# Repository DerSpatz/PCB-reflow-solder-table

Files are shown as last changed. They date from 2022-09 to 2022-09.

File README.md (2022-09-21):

# PCB-reflow-solder-table
Table version of the PCB heat plate with advanced features and swappable heat plate

This design is not yet tested and was not built yet.
Currently there's no firmware yet. I am not able to write the code, so feel free to contribute.
 
Schematic is pretty well documented, you can find most info you'll need there.

Todo:
- write firmware
- check actual mechanical device
- write better readme ;-)

Send me a message if you need gerbers for the actual heat plate.

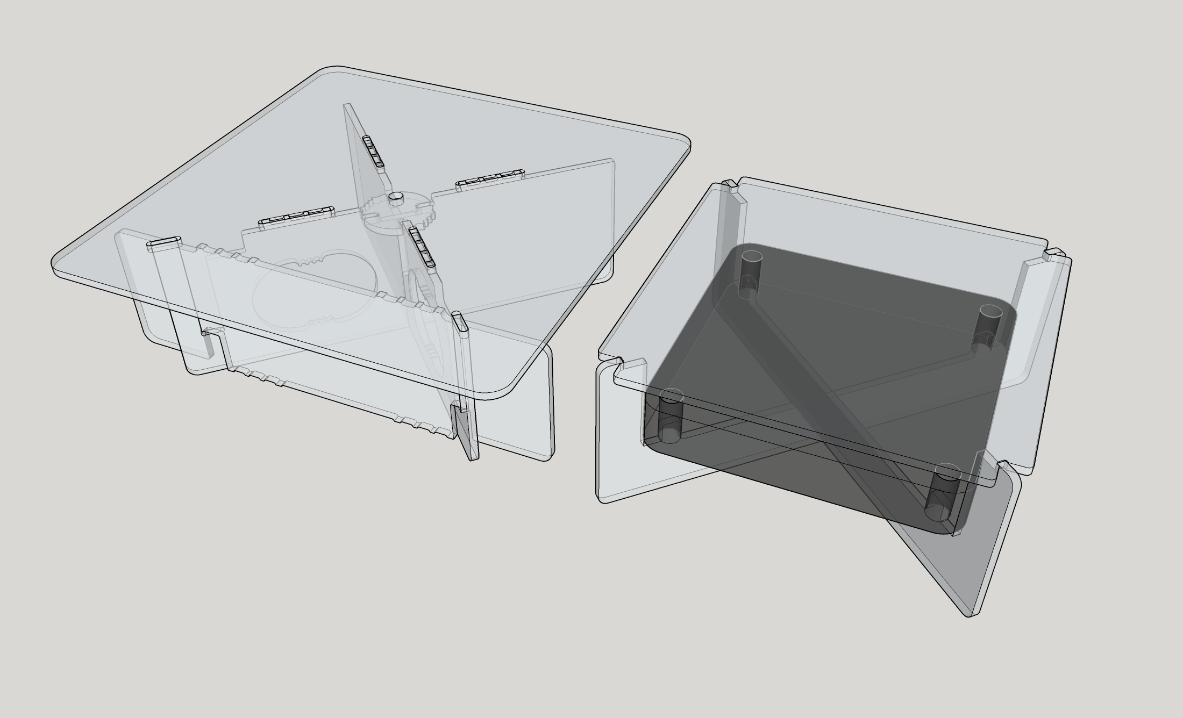
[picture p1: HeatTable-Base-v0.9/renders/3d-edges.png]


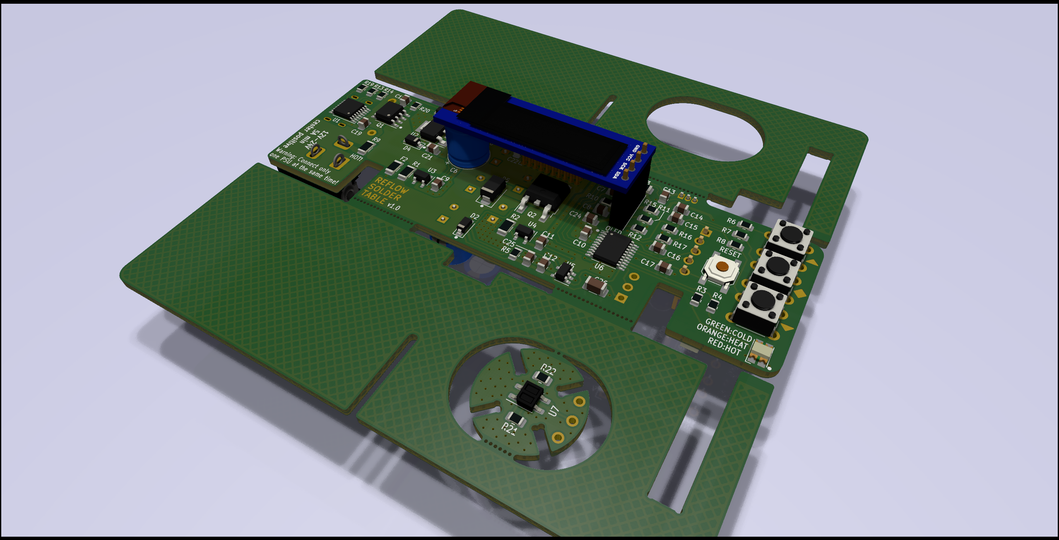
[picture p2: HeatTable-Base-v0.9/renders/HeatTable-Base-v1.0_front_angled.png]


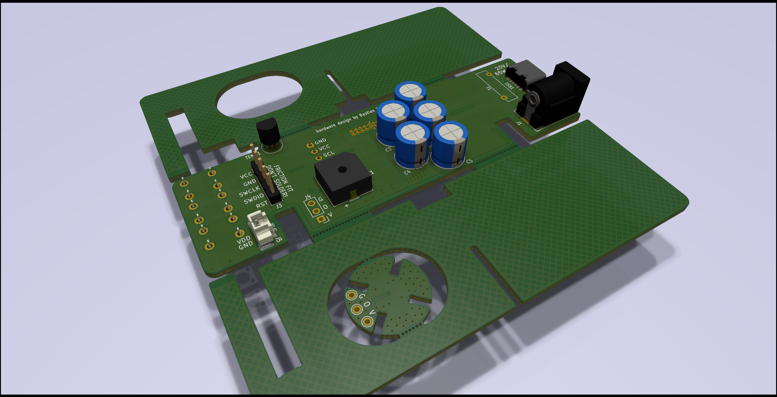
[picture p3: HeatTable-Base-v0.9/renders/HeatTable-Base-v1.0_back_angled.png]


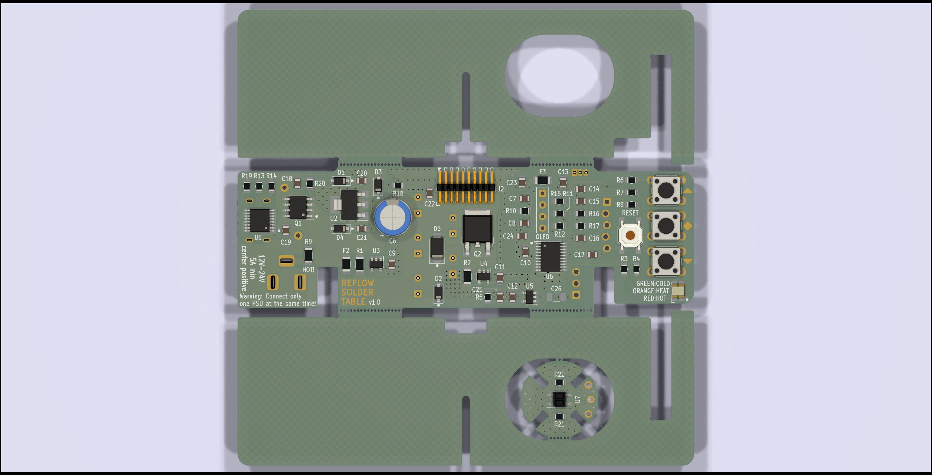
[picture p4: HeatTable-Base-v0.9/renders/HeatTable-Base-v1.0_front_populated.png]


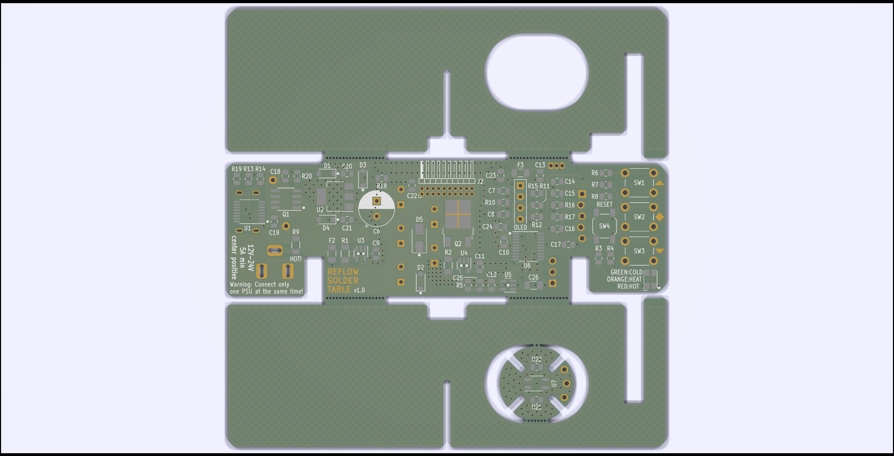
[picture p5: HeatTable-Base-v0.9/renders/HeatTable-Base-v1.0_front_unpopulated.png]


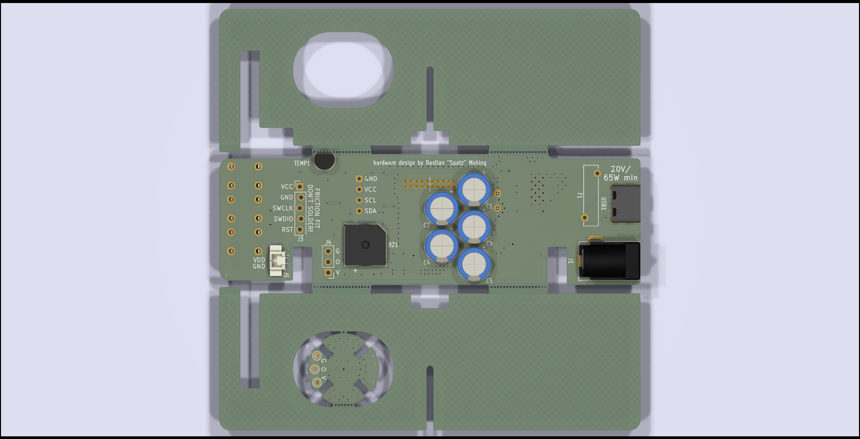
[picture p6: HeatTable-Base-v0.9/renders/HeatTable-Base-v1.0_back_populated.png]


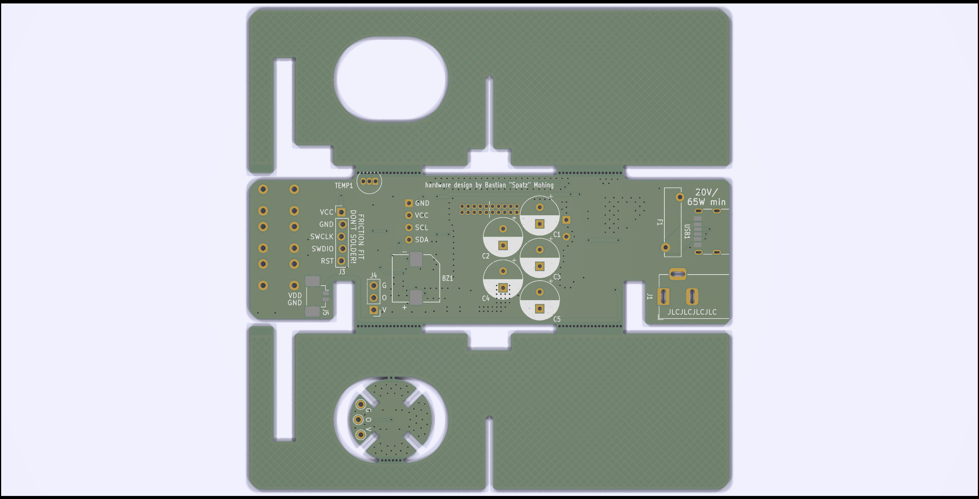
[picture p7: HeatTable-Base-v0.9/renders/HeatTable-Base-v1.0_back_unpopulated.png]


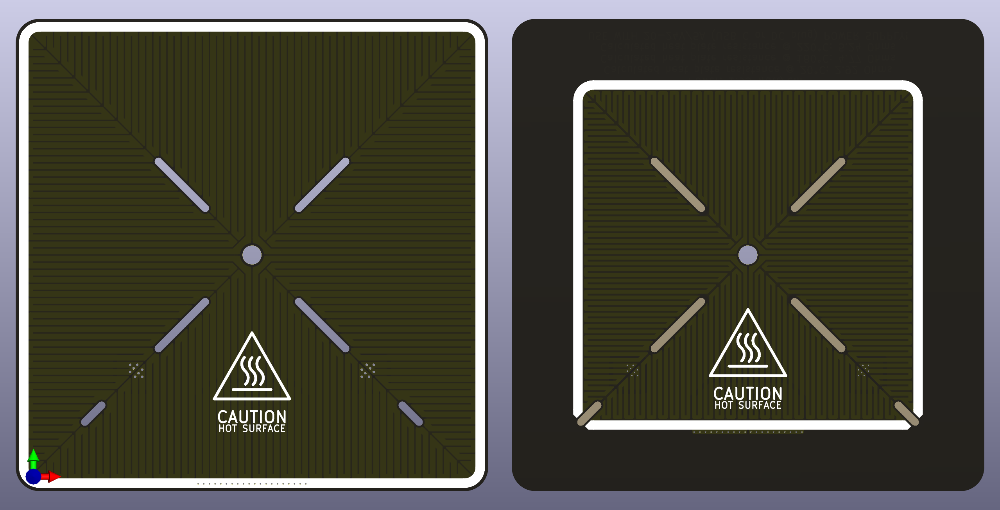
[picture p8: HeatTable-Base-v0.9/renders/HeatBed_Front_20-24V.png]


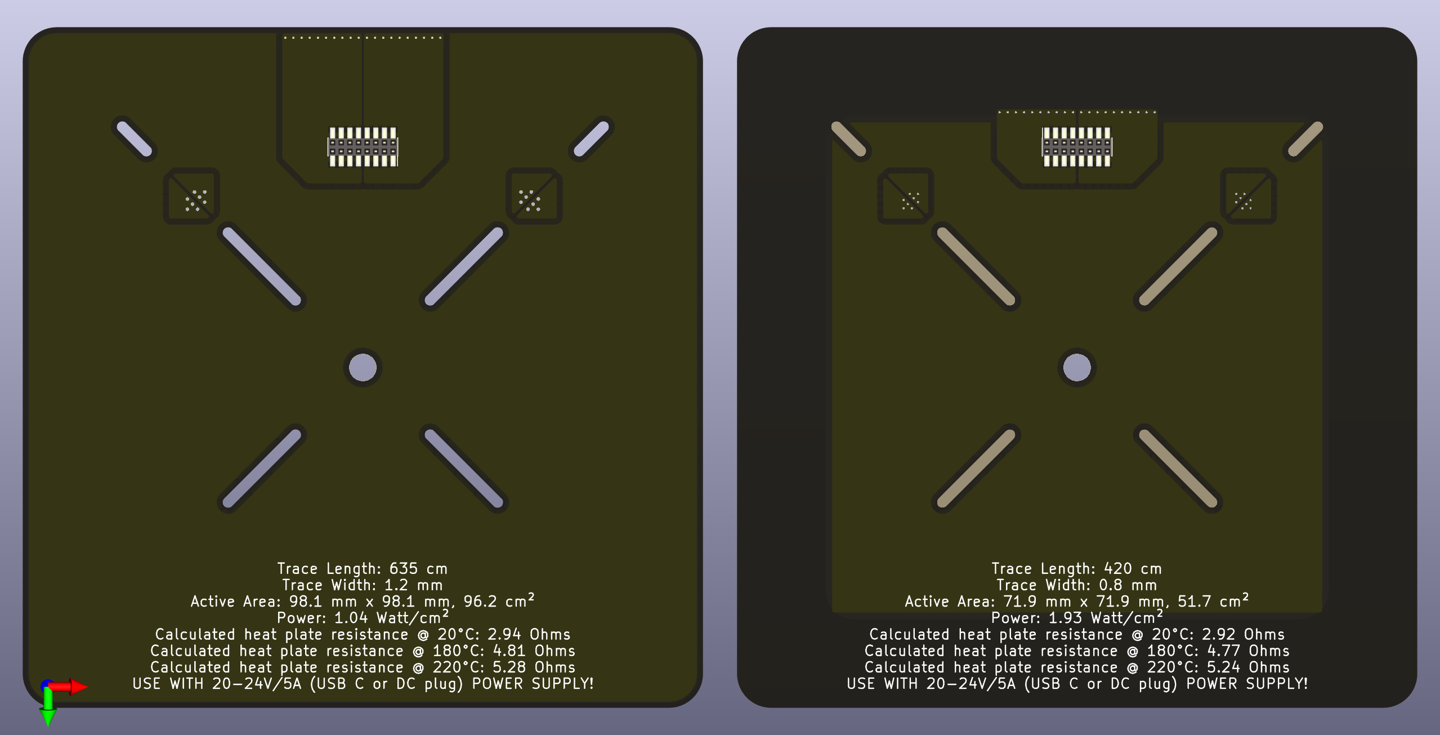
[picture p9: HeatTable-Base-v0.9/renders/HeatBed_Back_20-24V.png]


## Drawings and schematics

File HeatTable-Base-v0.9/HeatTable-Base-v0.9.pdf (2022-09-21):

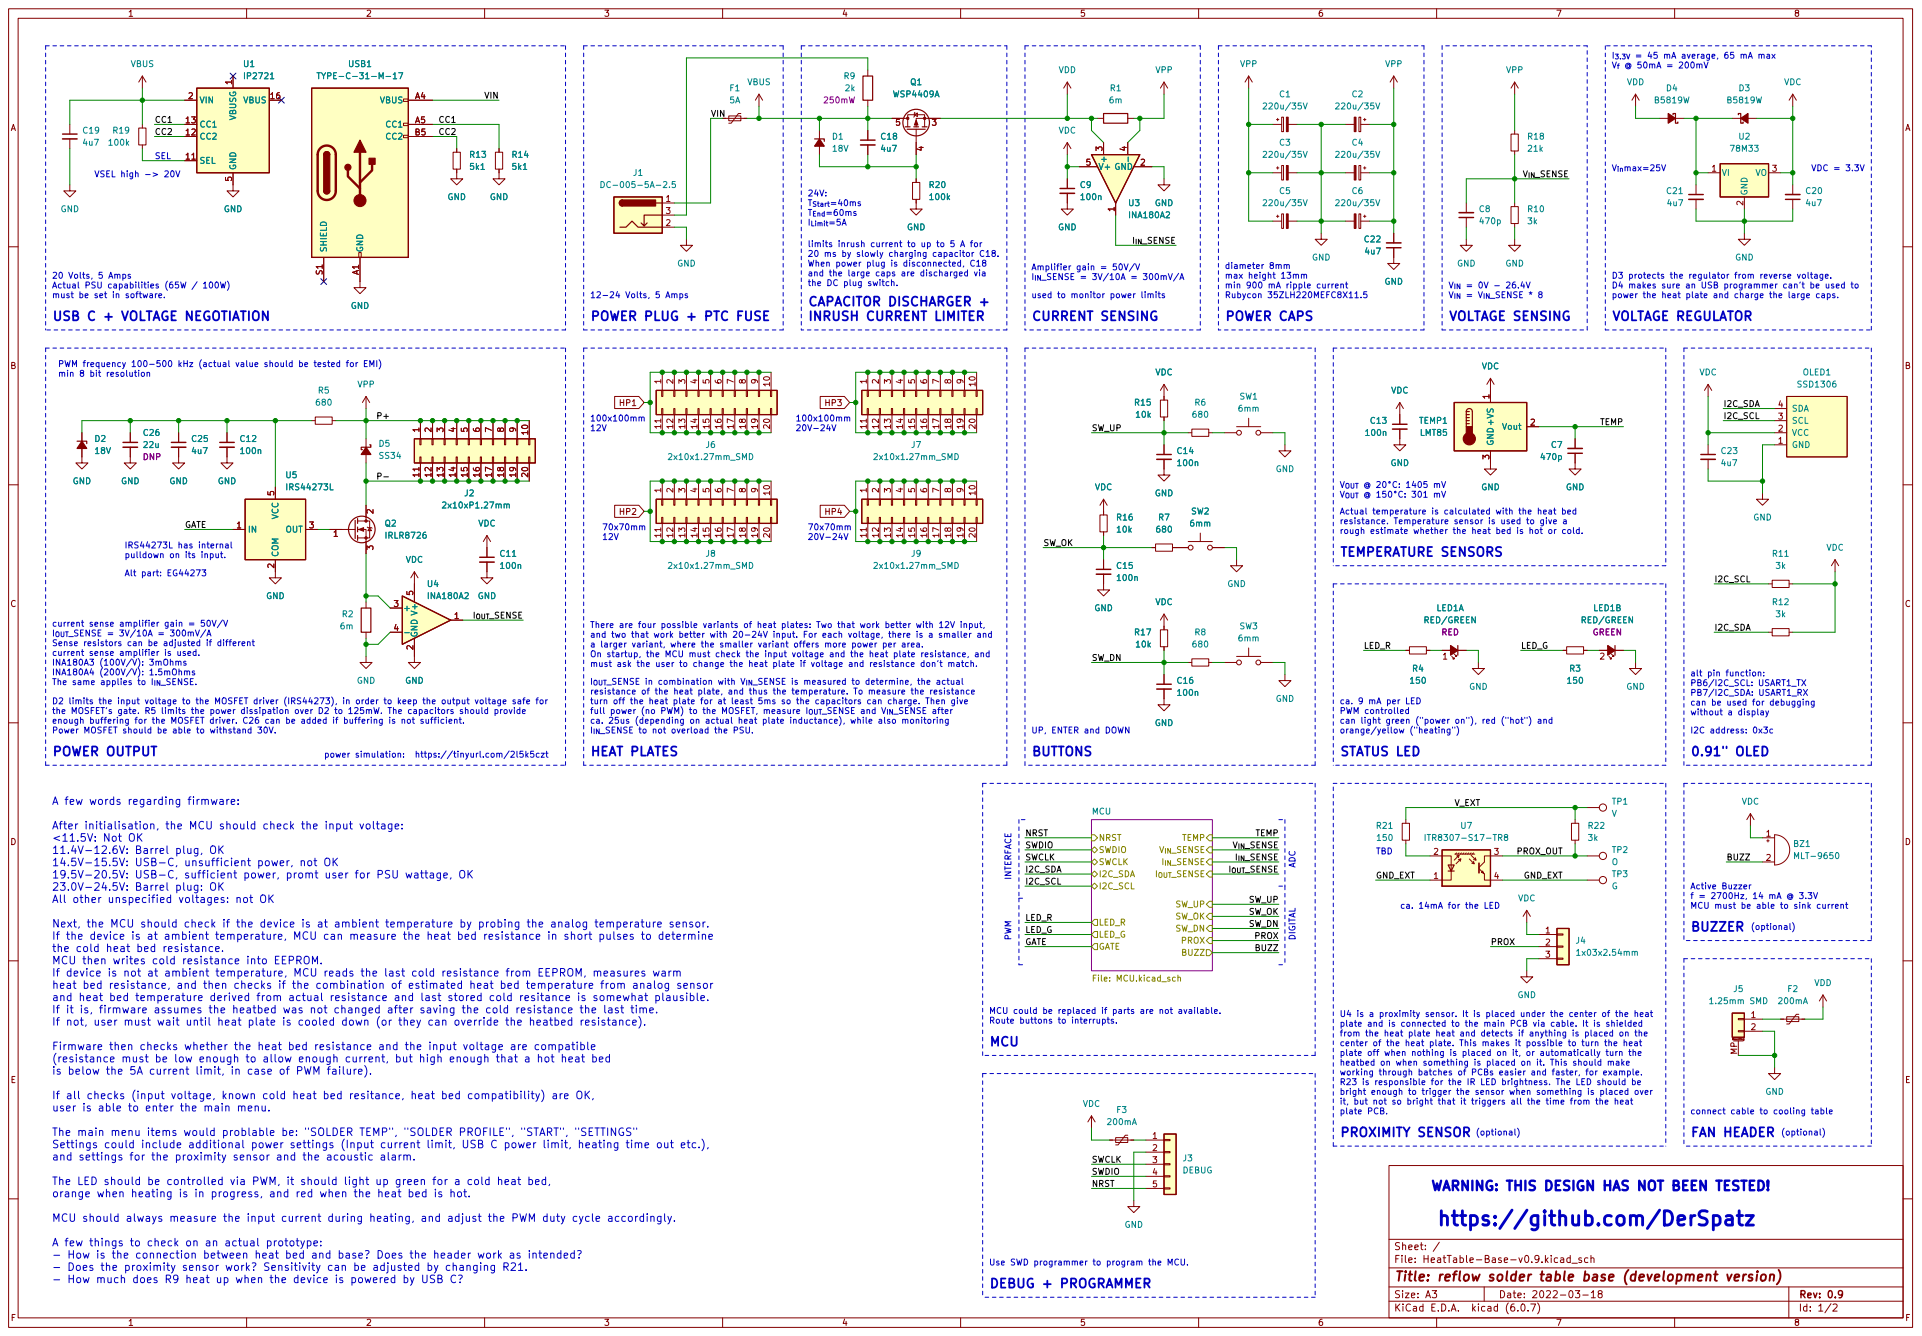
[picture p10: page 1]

1 SEL 11 CC2 12 CC1 13 VBUS 16 VIN 2 GND

Actual PSU capabilities (65W / 100W) must be set in software. VSEL high -> 20V

limits inrush current to up to 5 A for
20 ms by slowly charging capacitor C18.
When power plug is disconnected, C18
and the large caps are discharged via
the DC plug switch.
CAPACITOR DISCHARGER +
INRUSH CURRENT LIMITER

Amplifier gain = 50V/V
I_{IN}_SENSE = 3V/10A = 300mV/A
used to monitor power limits
f = 2700Hz, 14 mA @ 3.3V MCU must be able to sink current CURRENT SENSING

diameter 8mm
max height 13mm
min 900 mA ripple current
Rubycon 35ZLH220MEFC8X11.5

D3 protects the regulator from reverse voltage.
D4 makes sure an USB programmer can't be used to
power the heat plate and charge the large caps.
VOLTAGE REGULATOR

PWM frequency 100-500 kHz (actual value should be tested for EMI) min 8 bit resolution USB C + VOLTAGE NEGOTIATION

POWER PLUG + PTC FUSE

2 3 GND GND GND GND GND

Actual temperature is calculated with the heat bed

resistance. Temperature sensor is used to give a
rough estimate whether the heat bed is hot or cold.
TEMPERATURE SENSORS

current sense amplifier gain = 50V/V
I_{OUT}_SENSE = 3V/10A = 300mV/A
Sense resistors can be adjusted if different
current sense amplifier is used.
INA180A3 (100V/V): 3mOhms
INA180A4 (200V/V): 1.5mOhms
The same applies to I_{IN}_SENSE.

There are four possible variants of heat plates: Two that work better with 12V input,
and two that work better with 20-24V input. For each voltage, there is a smaller and
a larger variant, where the smaller variant offers more power per area.
On startup, the MCU must check the input voltage and the heat plate resistance, and
must ask the user to change the heat plate if voltage and resistance don't match.
I_{OUT}_SENSE in combination with V_{IN}_SENSE is measured to determine, the actual
resistance of the heat plate, and thus the temperature. To measure the resistance
turn off the heat plate for at least 5ms so the capacitors can charge. Then give
full power (no PWM) to the MOSFET, measure I_{OUT}_SENSE and V_{IN}_SENSE after
ca. 25us (depending on actual heat plate inductance), while also monitoring
I_{IN}_SENSE to not overload the PSU.
HEAT PLATES

PB7/I2C_SDA: USART1_RX
can be used for debugging
without a display

D2 limits the input voltage to the MOSFET driver (IRS44273), in order to keep the output voltage safe for
the MOSFET's gate. R5 limits the power dissipation over D2 to 125mW. The capacitors should provide
enough buffering for the MOSFET driver. C26 can be added if buffering is not sufficient. Power MOSFET should be able to withstand 30V. A few words regarding firmware:

ca. 9 mA per LED
PWM controlled
can light green ("power on"), red ("hot") and
orange/yellow ("heating")
STATUS LED

After initialisation, the MCU should check the input voltage:
<11.5V: Not OK
11.4V-12.6V: Barrel plug, OK
14.5V-15.5V: USB-C, unsufficient power, not OK
19.5V-20.5V: USB-C, sufficient power, promt user for PSU wattage, OK
23.0V-24.5V: Barrel plug: OK
All other unspecified voltages: not OK

ca. 14mA for the LED

Next, the MCU should check if the device is at ambient temperature by probing the analog temperature sensor.
If the device is at ambient temperature, MCU can measure the heat bed resistance in short pulses to determine
the cold heat bed resistance.
MCU then writes cold resistance into EEPROM.
If device is not at ambient temperature, MCU reads the last cold resistance from EEPROM, measures warm
heat bed resistance, and then checks if the combination of estimated heat bed temperature from analog sensor
and heat bed temperature derived from actual resistance and last stored cold resitance is somewhat plausible.
If it is, firmware assumes the heatbed was not changed after saving the cold resistance the last time.
If not, user must wait until heat plate is cooled down (or they can override the heatbed resistance).

MCU could be replaced if parts are not available.
Route buttons to interrupts.
MCU

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

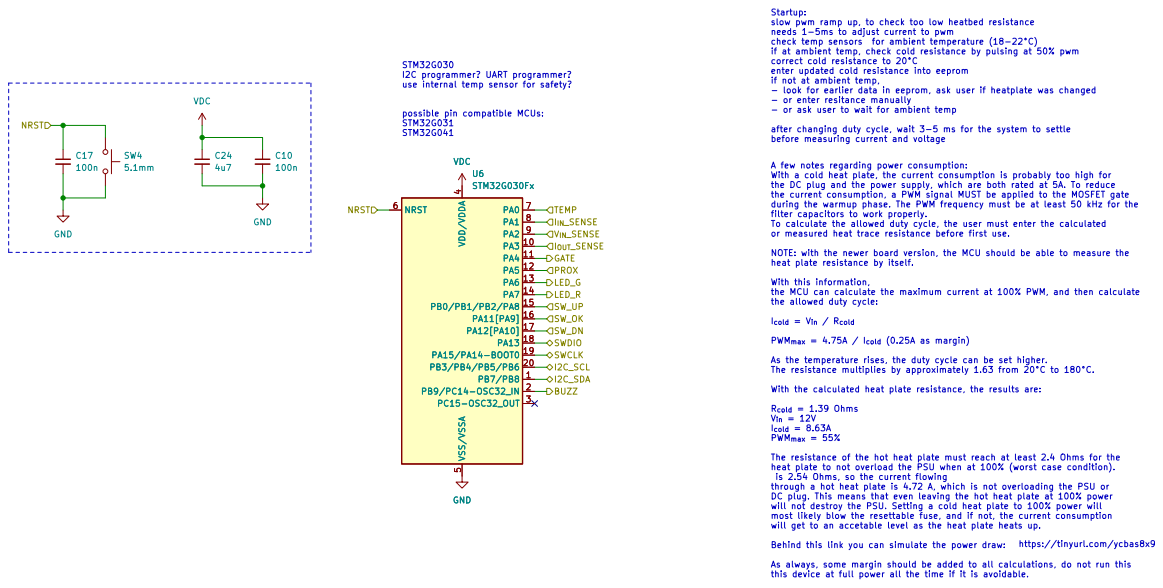
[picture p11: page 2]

Startup:
slow pwm ramp up, to check too low heatbed resistance
needs 1-5ms to adjust current to pwm
if at ambient temp, check cold resistance by pulsing at 50% pwm
enter updated cold resistance into eeprom
if not at ambient temp,
- look for earlier data in eeprom, ask user if heatplate was changed
- or enter resitance manually
- or ask user to wait for ambient temp
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

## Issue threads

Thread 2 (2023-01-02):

USB-C CC not connected

ldab, 2023-01-02:
When I CTRL+F the schematic PDF I do not see CC1 and CC2 connected to anything that could possibly set the source to 20V3A, I believe that is missing.

Closed 2023-01-02.
